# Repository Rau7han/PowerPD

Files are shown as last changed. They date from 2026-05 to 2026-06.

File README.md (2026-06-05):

# PowerPD - ESP32 USB-C PD/PPS Programmable Power Supply

<div align="center">
  
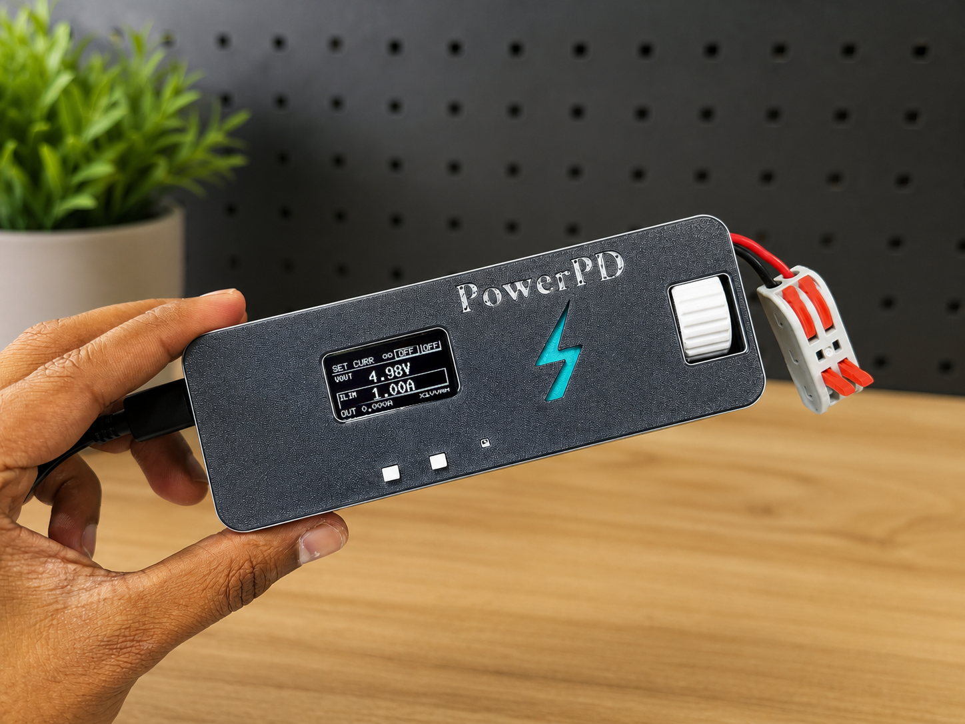
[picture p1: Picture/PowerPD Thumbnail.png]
PowerPD Thumbnail


**A Compact, Feature-Rich USB-C Power Delivery Programmable Bench Power Supply**





</div>

---

## 📋 Table of Contents

- [Introduction](#introduction)
- [Features](#features)
- [Specifications](#specifications)
- [How It Works](#how-it-works)
- [Hardware Overview](#hardware-overview)
- [Gallery](#gallery)
- [Repository Files](#repository-files)
- [Getting Started](#getting-started)
- [Project Links](#project-links)
- [License & Author](#license--author)

---

## Introduction

PowerPD is an innovative ESP32-based **USB-C Power Delivery (PD) and Power Profile Specification (PPS)** programmable bench power supply. It leverages modern USB-C PD technology to provide a flexible, programmable power source that can deliver various voltage and current levels. 

Perfect for **electronics enthusiasts, makers, and professionals** who need a compact, feature-rich power supply for prototyping, testing, and DIY projects.

---

## ✨ Features

- ⚡ **USB-C Power Delivery Support** - Harness power from modern USB-C PD chargers (5V-20V)
- 🎛️ **Programmable Voltage & Current** - User-configurable output with real-time control
- 🔧 **ESP32 Powered** - Full-featured microcontroller for advanced functionality
- 📱 **Interactive Menu System** - Intuitive interface for easy configuration
- 📊 **Real-time Monitoring** - Display current voltage and current output
- 🎓 **Easy Programming** - UART to USB interface for firmware updates
- 💾 **Compact Design** - Space-efficient bench power supply form factor
- 🏗️ **Open Source** - All designs, schematics, and code included

---

## Specifications

| Parameter | Value |
|---|---|
| **Microcontroller** | ESP32 |
| **Input** | USB-C Power Delivery / PPS Charger |
| **Output Voltage Range** | 5V to 20V (via USB PD/PPS protocols) |
| **Programmable Voltage** | User-configurable voltage selection |
| **Programmable Current** | User-adjustable current limits |
| **Control Interface** | Interactive menu system via ESP32 |
| **Communication** | UART to USB interface for programming |
| **Form Factor** | Compact bench power supply |

---

## How It Works

The PowerPD system operates through a simple but powerful workflow:

1. **Power Input** 🔌
   - A USB-C PD/PPS charger supplies power to the system
   - The system negotiates the desired voltage with the charger

2. **ESP32 Control** 🧠
   - The ESP32 microcontroller manages voltage negotiation and current limiting
   - The AP33772S power manager IC provides precise voltage and current regulation

3. **User Configuration** ⚙️
   - Users set desired voltage and current values through an intuitive menu interface
   - Real-time feedback shows current operating parameters

4. **Power Output** ⚡
   - The regulated output is available as a programmable bench power supply
   - Suitable for powering various electronics projects and testing scenarios

---

## Hardware Overview

### 3D Model & Design

<div align="center">

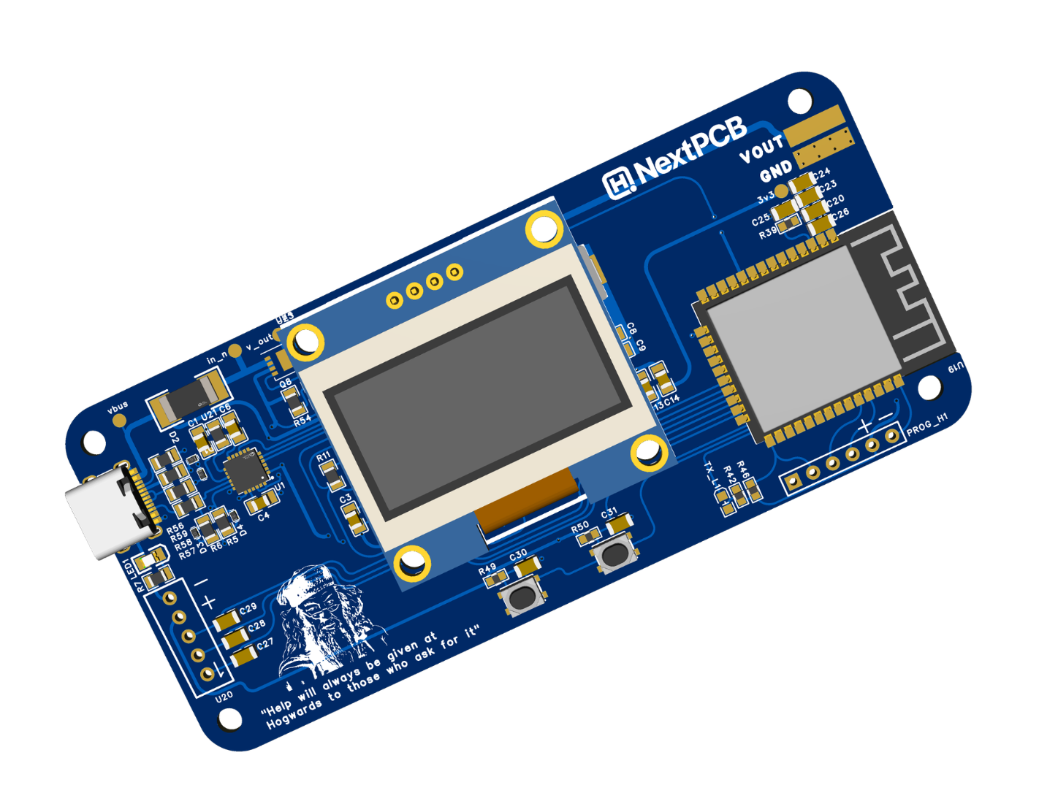
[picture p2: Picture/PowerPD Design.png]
PowerPD 3D Design


**3D Rendered View of PowerPD Enclosure**

</div>

<div align="center">

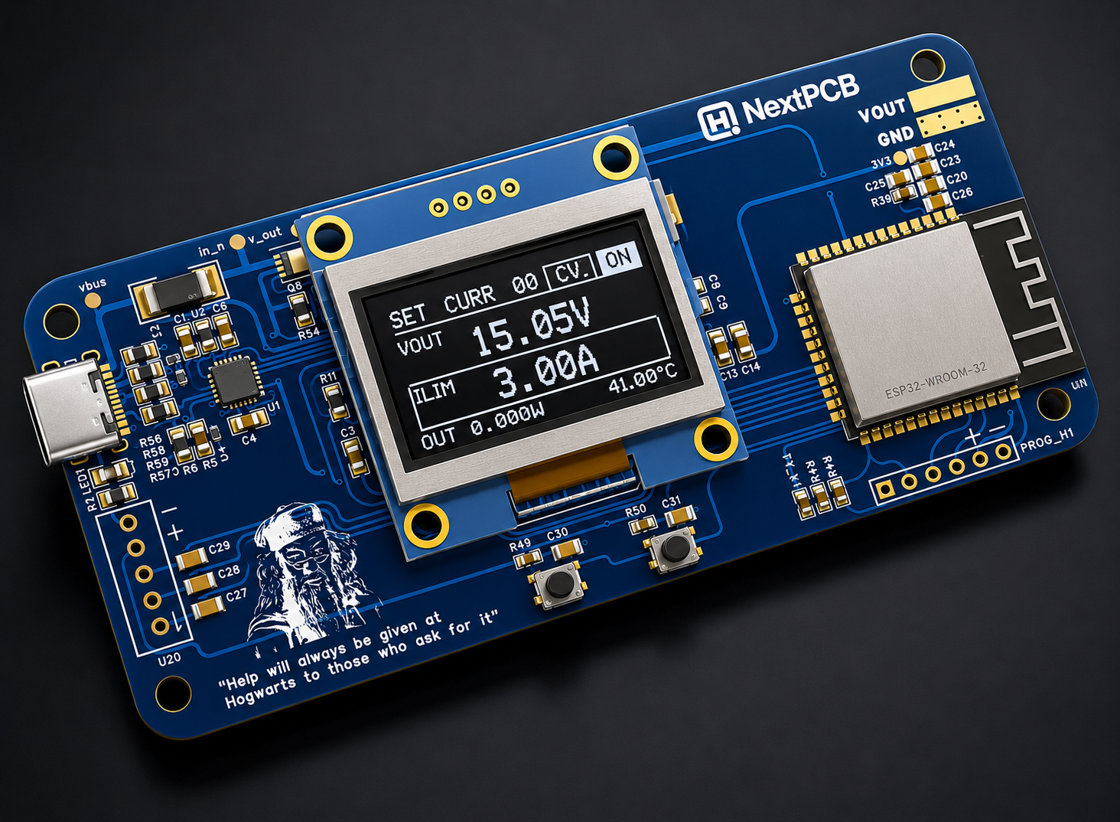
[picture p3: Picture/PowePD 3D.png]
PowerPD 3D Model


**3D-Printable Enclosure Model**

</div>

### PCB & Manufacturing

<div align="center">

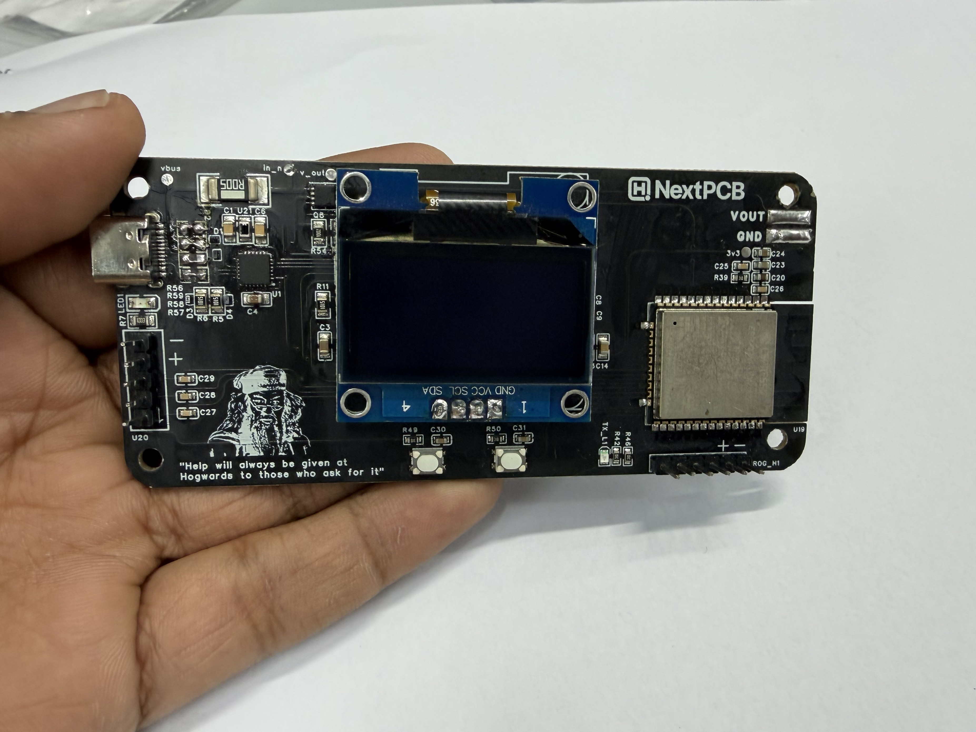
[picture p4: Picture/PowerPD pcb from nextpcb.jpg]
PowerPD PCB


**High-Quality PCB from NextPCB**

</div>

---

## Gallery

### Power Output Demonstrations

<div align="center">

#### 5V Output Mode
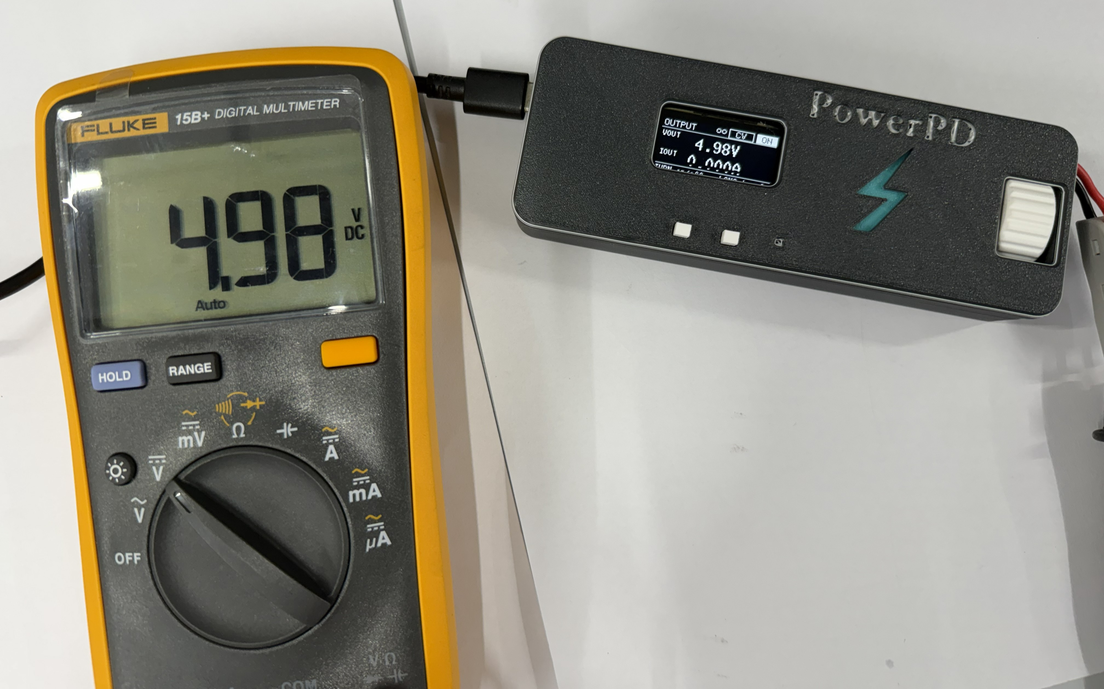
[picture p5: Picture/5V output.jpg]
5V Output


**PowerPD delivering stable 5V output**

</div>

<div align="center">

#### 16V Output Mode
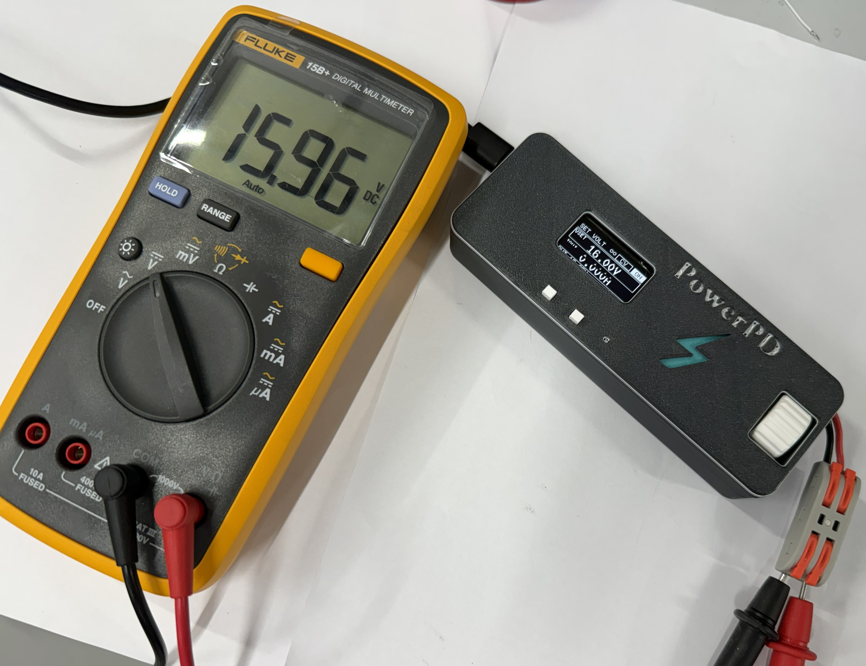
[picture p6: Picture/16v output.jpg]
16V Output


**PowerPD delivering high-voltage 16V output**

</div>

<div align="center">

#### 20V Output Mode
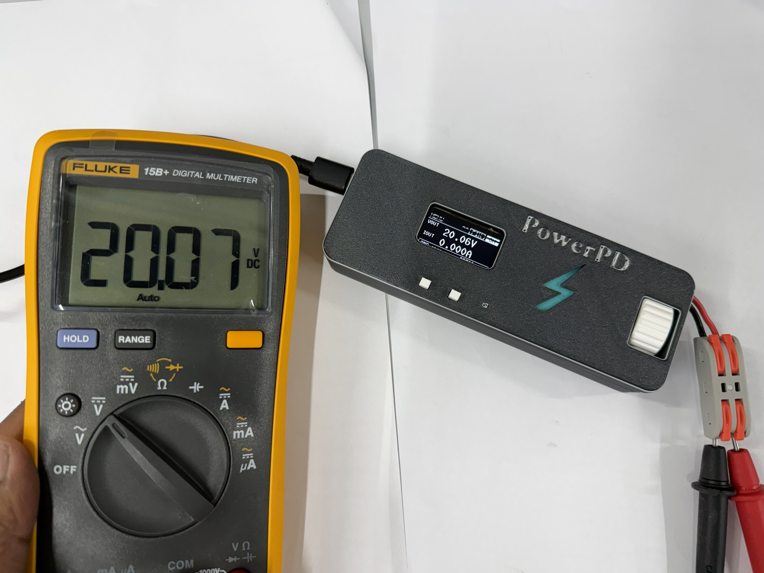
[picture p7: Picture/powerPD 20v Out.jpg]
20V Output


**Maximum 20V output capability**

</div>

<div align="center">

#### Alternative 5V Output View
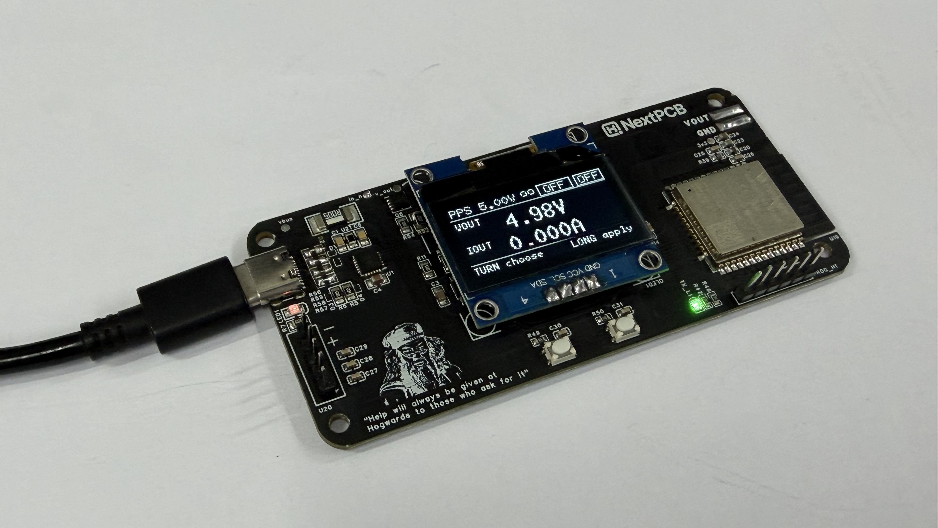
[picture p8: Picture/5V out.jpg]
5V Output Secondary


**5V output measurement configuration**

</div>

<div align="center">

#### 5V Output (Scaled)
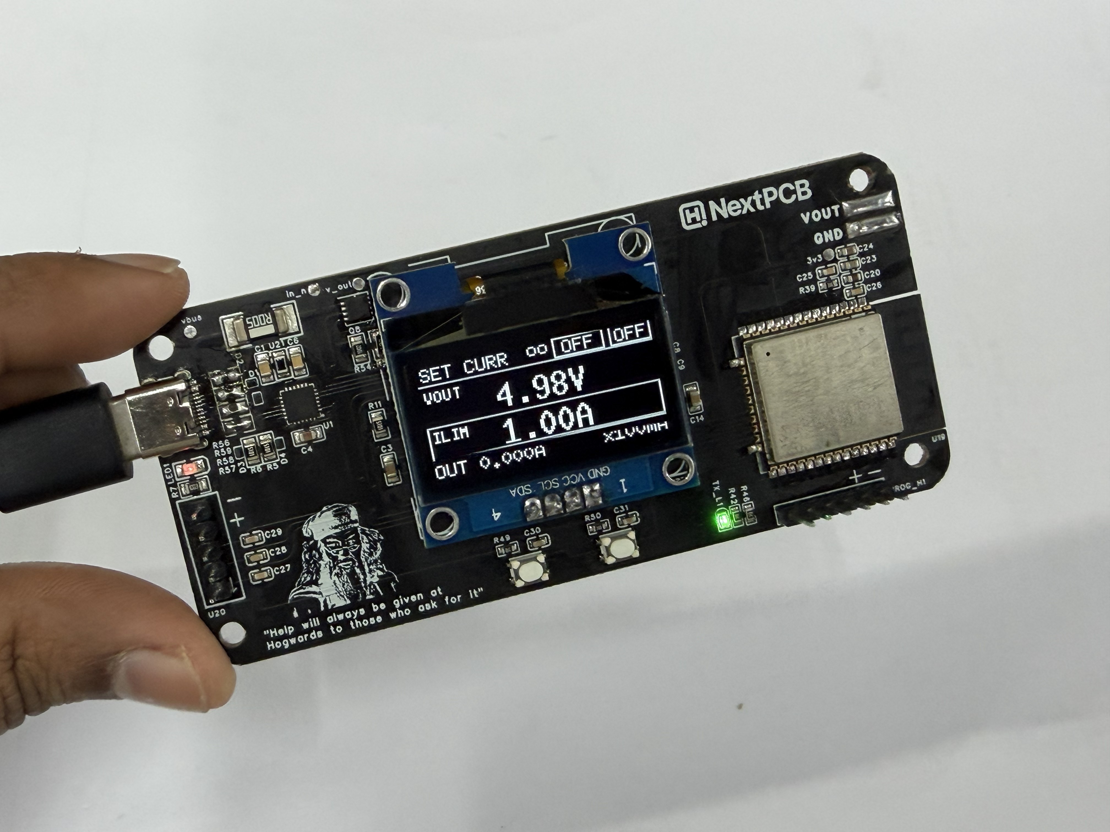
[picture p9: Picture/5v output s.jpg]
5V Output Scaled


**Compact 5V output demonstration**

</div>

### Control Interface & Menu System

<div align="center">

#### Main Menu Display
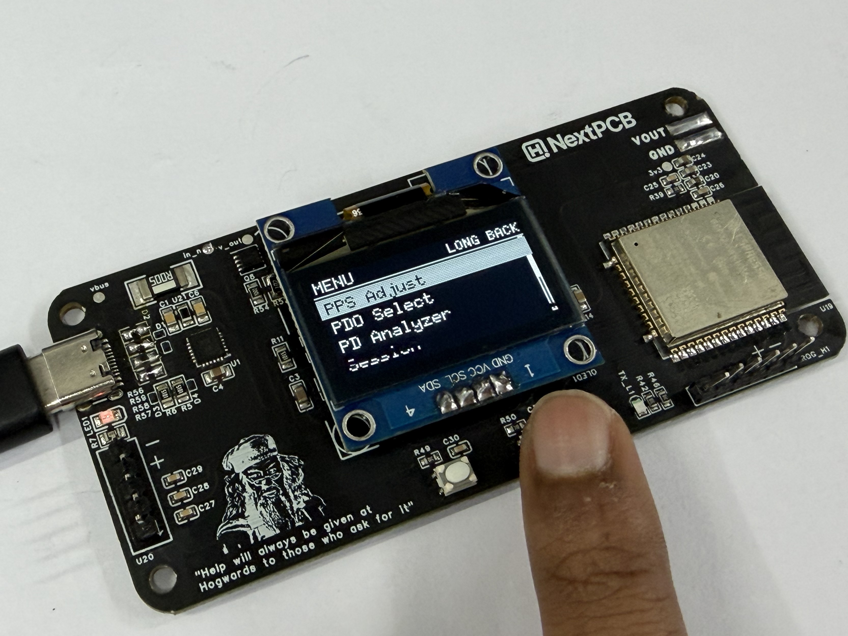
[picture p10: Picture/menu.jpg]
Menu System


**Interactive menu system for voltage/current selection**

</div>

<div align="center">

#### PPS Adjustment Menu
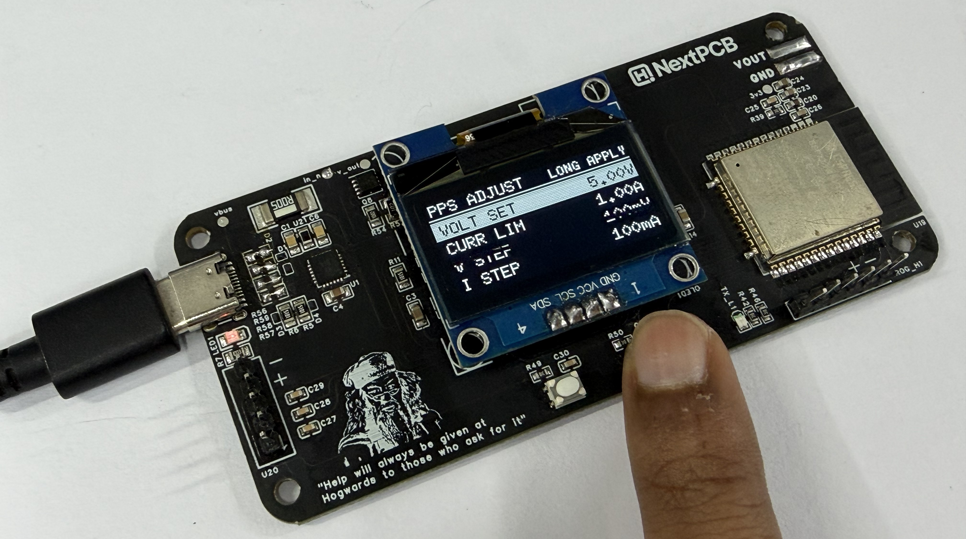
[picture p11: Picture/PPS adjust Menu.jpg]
PPS Menu


**Power Profile Specification (PPS) adjustment interface**

</div>

### Integration & Monitoring

<div align="center">

#### Live Working Setup
PowerPD Working

**PowerPD in action - live demonstration**

</div>

<div align="center">

#### Adafruit IoT Dashboard
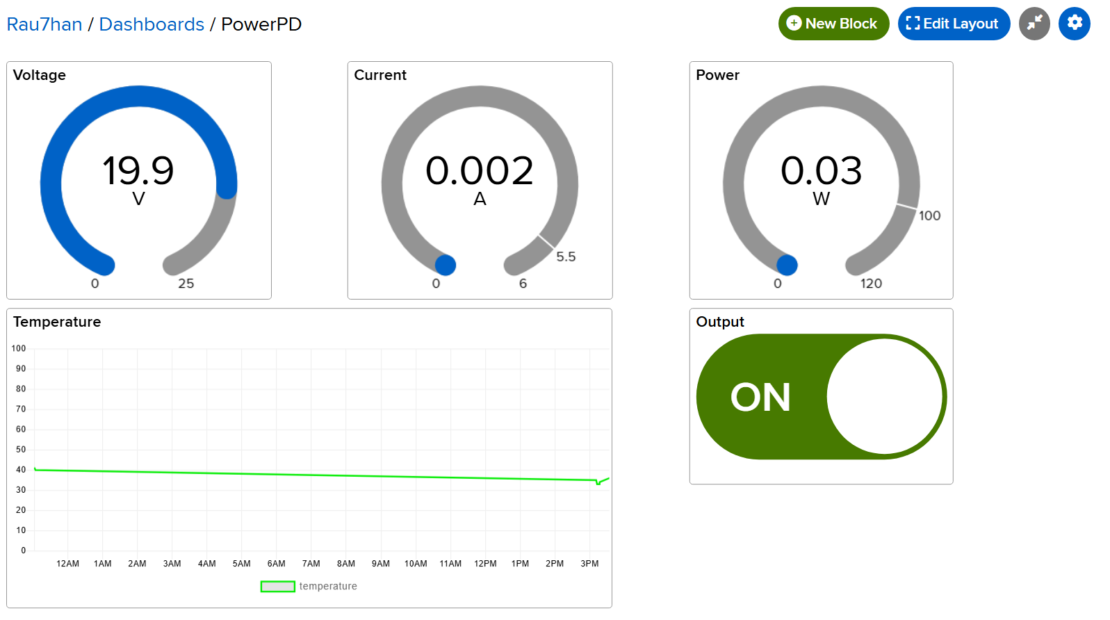
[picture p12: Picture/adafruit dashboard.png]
Adafruit Dashboard


**IoT monitoring with Adafruit IO integration**

</div>

<div align="center">

#### Adafruit IoT Integration
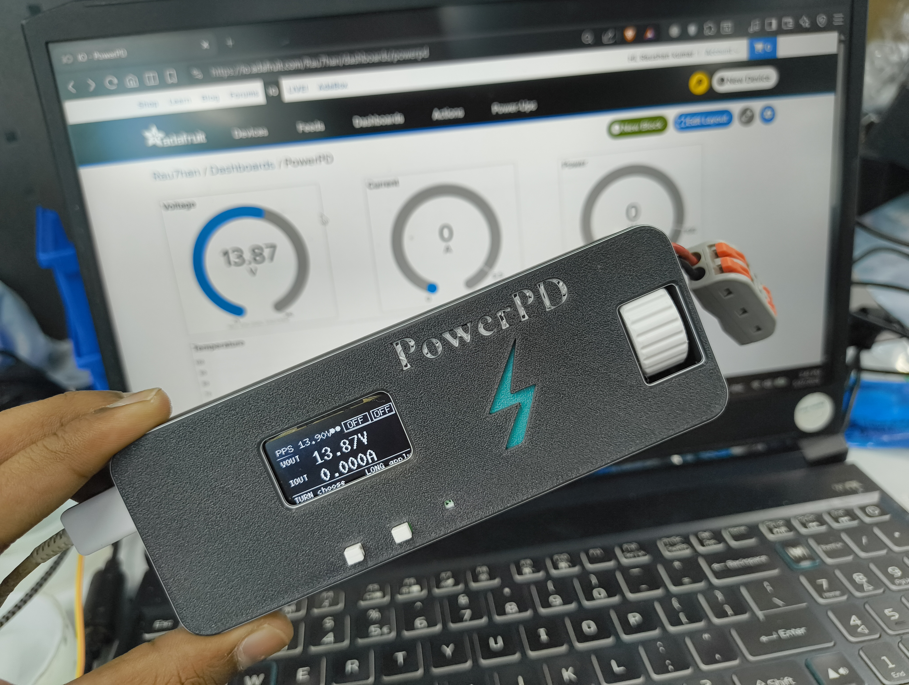
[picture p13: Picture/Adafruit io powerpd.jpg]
Adafruit Integration


**Remote monitoring and control via Adafruit IoT**

</div>

### Development & Programming

<div align="center">

#### Programming Interface
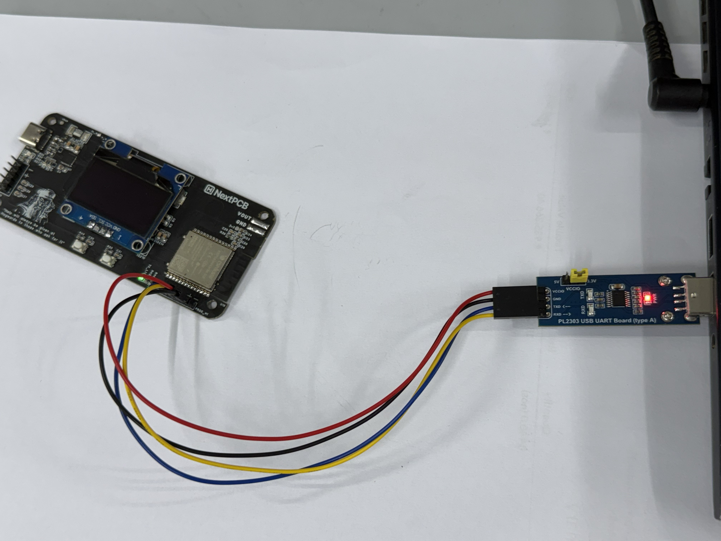
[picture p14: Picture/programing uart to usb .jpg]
UART to USB Programming


**UART to USB interface for firmware programming**

</div>

<div align="center">

#### NextPCB Promotion
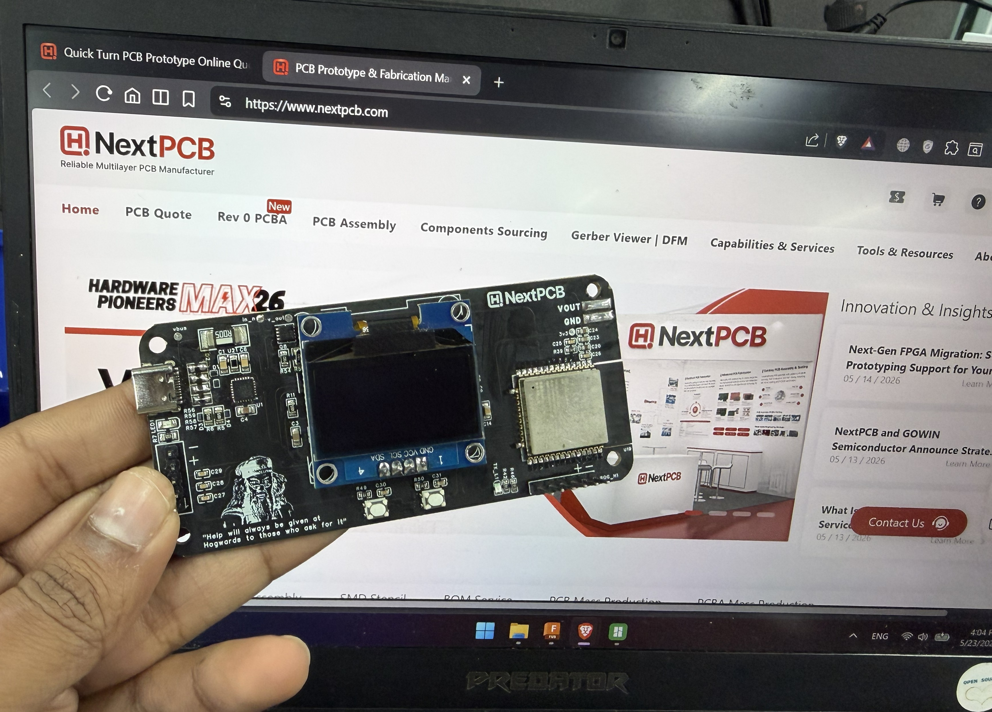
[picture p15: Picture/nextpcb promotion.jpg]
NextPCB Promotion


**PCB fabrication courtesy of NextPCB**

</div>

---

## Repository Files

| Directory | Description |
|---|---|
| **Firmware** | ESP32 Arduino code (`PowerPD.ino`) with AP33772S power manager driver for voltage and current control |
| **Gerber Files** | Complete PCB manufacturing files including schematics BOM and centroid files ready for fabrication |
| **Picture** | High-quality project photos, gallery images, and demonstration screenshots |
| **PowerPD Schematic** | Detailed circuit schematics for reference and replication |
| **STL** | 3D-printable enclosure files for project housing |

---

## Getting Started

### Prerequisites
- ESP32 Development Board or PowerPD PCB
- USB-C Power Delivery (PD) Charger (5V-20V recommended)
- Arduino IDE with ESP32 support
- UART to USB adapter (CH340G or similar) for programming

### Quick Start

1. **Clone/Download the Repository**
   ```bash
   git clone https://github.com/Rau7han/PowerPD.git
   ```

2. **Prepare the Firmware**
   - Open `Firmware/PowerPD.ino` in Arduino IDE
   - Include the `AP33772S.cpp` and `AP33772S.h` libraries
   - Select ESP32 board and appropriate COM port

3. **Upload Firmware**
   - Connect UART to USB adapter to programming header
   - Upload the firmware to your ESP32

4. **Power On**
   - Connect USB-C PD charger to the PowerPD input
   - The system will boot and display the menu

5. **Configure Output**
   - Use the menu system to select desired voltage (5V-20V)
   - Adjust current limits as needed
   - Your programmable power supply is ready to use!

---

## Project Links

| Platform | Link |
|---|---|
| **Hackster.io** | [PowerPD ESP32 USB-C PD/PPS Programmable Power Supply](https://www.hackster.io/rau7han/powerpd-esp32-usb-c-pd-pps-programmable-power-supply-c2c4c0) |
| **Hackaday.io** | [PowerPD - ESP32 USB-C PD/PPS Bench Power Supply](https://hackaday.io/project/205791-powerpd-esp32-usb-c-pdpps-bench-power-supply) |
| **Instructables** | [PowerPD: ESP32 USB-C PD Bench Power Supply](https://www.instructables.com/PowerPD-ESP32-USB-C-PD-Bench-Power-Supply/) |

---

## License & Author

**Author**: [Rau7han](https://github.com/Rau7han)

**License**: See repository for detailed license information

---

<div align="center">

**Contributions, suggestions, and feedback are welcome!** 🎉

If you build PowerPD, we'd love to hear about it! Share your projects and improvements.

</div>

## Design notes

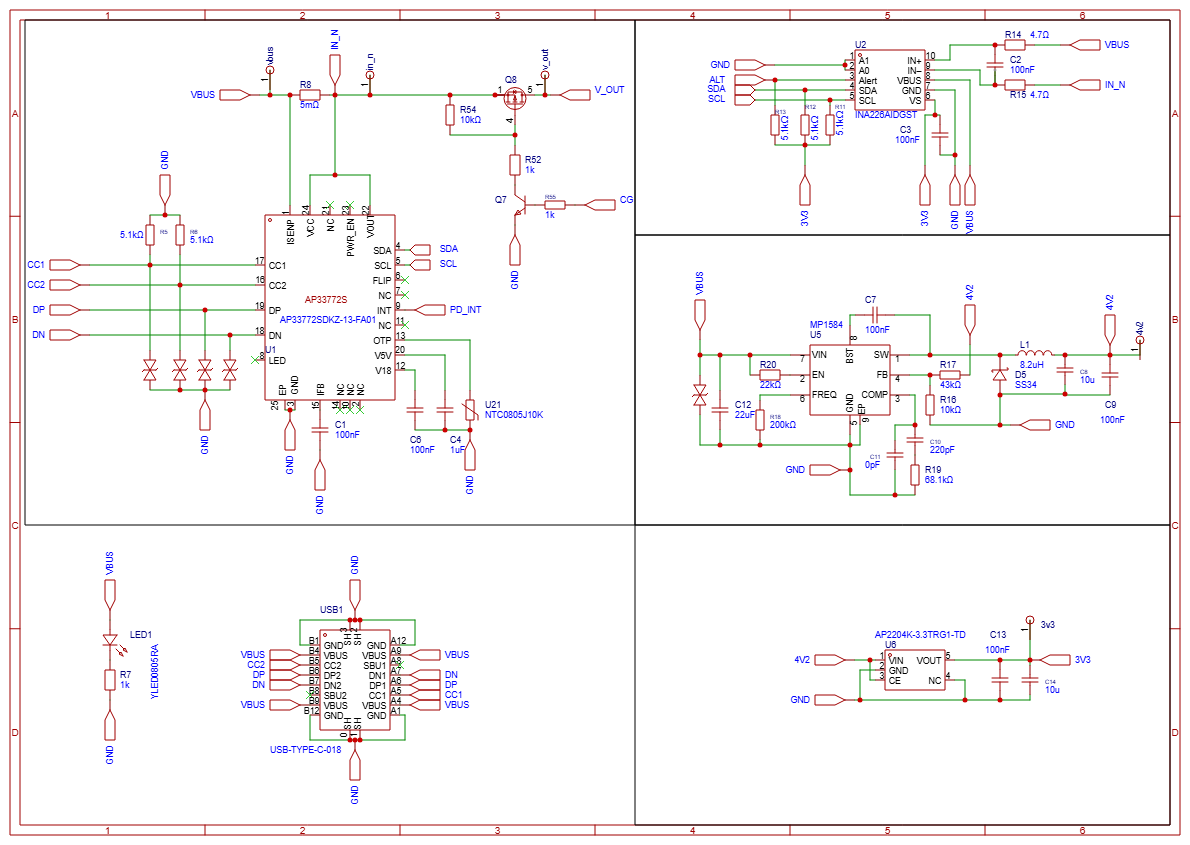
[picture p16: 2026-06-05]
PowerPD Schematic/PowerPD Schematic 1.png

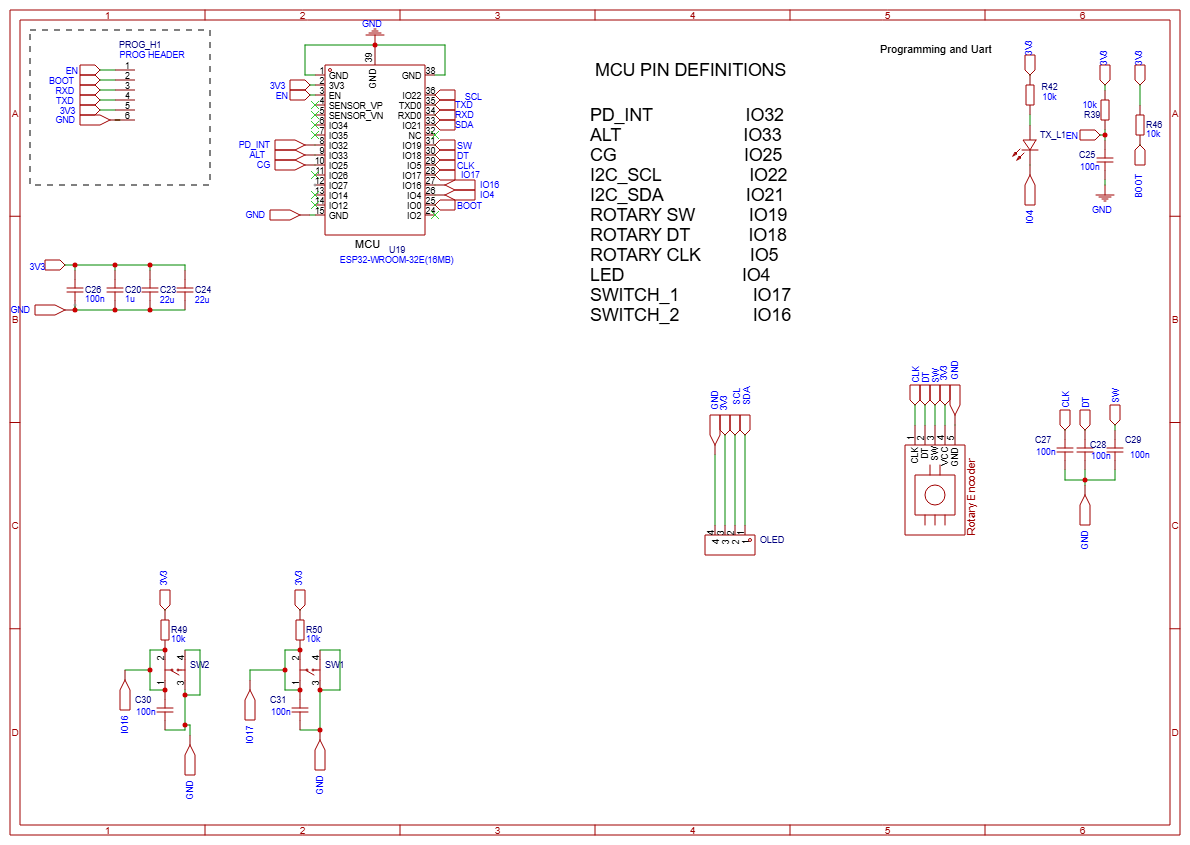
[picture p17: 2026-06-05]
PowerPD Schematic/PowerPD Sch 2.png

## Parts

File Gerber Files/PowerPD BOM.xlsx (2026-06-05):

No. | Quantity | Comment | Designator | Footprint | Value | Manufacturer Part | Manufacturer | Supplier Part | Supplier
1 | 5 | testPoint | 3v3,4v2,in_n,vbus,v_out | testPoint
2 | 5 | 100nF | C1,C6,C7,C9,C13 | C0805 | 100nF | C0805B104K100NT | TORCH(火炬) | C17702773 | LCSC
3 | 2 | 100nF | C2,C3 | C0805 | 100nF | CT41G-0805-2X1-50V-0.1uF-M(N) | TORCH(火炬) | C138340 | LCSC
4 | 1 | 1uF | C4 | C0805 | 1uF | NC0805B105K101CDDN | HUI JU(汇聚) | C19185643 | LCSC
5 | 2 | 10u | C8,C14 | C0805 | 10u | CL21B224KBFNNNE | SAMSUNG(三星) |  | LCSC
6 | 1 | 220pF | C10 | C0805 | 220pF | CC0805KRX7R9BB221 | YAGEO(国巨) | C107145 | LCSC
7 | 1 | 0pF | C11 | C0805 | 0pF | CC0805KRX7R9BB221 | YAGEO(国巨) |  | LCSC
8 | 1 | 22uF | C12 | C0805 | 22uF | CL21A226MAQNNNE | SAMSUNG(三星) | C45783 | LCSC
9 | 1 | 1u | C20 | C0603
10 | 2 | 22u | C23,C24 | C0603
11 | 6 | 100n | C25,C27,C28,C29,C30,C31 | C0603 |  | 0805 | null | C9900012713 | LCSC
12 | 1 | 100n | C26 | C0603
 | 4 | D5V0H1B2LP-7B | D1,D2,D3,D4 |  |  | D5V0H1B2LP-7B
13 | 1 | PESD1ETH1GXLS-QYL | D6 | SOD-882_L1.0-W0.6-BI-1 |  | PESD1ETH1GXLS-QYL | Nexperia(安世) | C553450 | LCSC
14 | 1 | SS34 | D5 | SMA_L4.3-W2.6-LS5.2-RD |  | SS34 | MDD(辰达半导体) | C8678 | LCSC
15 | 1 | 8.2uH | L1 | IND-SMD_L7.3-W6.8 | 8.2uH | MWSA0603S-8R2MT | Sunlord(顺络) | C408450 | LCSC
16 | 1 | A-SP170R5C-A01-3T | LED1 | LED0805-FD |  | A-SP170R5C-A01-3T | YONGYUTAI(永裕泰) | C52989003 | LCSC
17 | 1 | OLED_4P_1.3\"-128*64 | OLED1 | OLED_4P_1.3\"-128*64 |  | DLC0130ANOB-W | DLC Display Co.,Ltd
18 | 1 | PROG HEADER | PROG_H1 | HDR-M-2.54_1X6 |  | New SchematicLib
19 | 1 | S8050 J3Y(RANGE:200-350) | Q7 | SOT-23-3_L3.0-W1.7-P0.95-LS2.9-BR |  | S8050 J3Y(RANGE:200-350) | CJ(江苏长电/长晶) | C2146 | LCSC
20 | 1 | Transistor_FET_DMP3013SFV | Q8 | Package_SON:Diodes_PowerDI3333-8 | DMP3013SFV-7
21 | 5 | 5.1kΩ | R5,R6,R11,R12,R13 | R0805 | 5.1kΩ | AC0805FR-075K1L | Tyohm(幸亚电阻) | C269748 | LCSC
22 | 2 | 1k | R7,R52 | R0805 | 1k | CRG0805F100K | TE Connectivity(泰科电子) |  | LCSC
23 | 1 | 5mΩ | R8 | RES-SMD_L6.4-W3.2-1 | 5mΩ | PA2512FKF070R005E | YAGEO(国巨) | C723365 | LCSC
24 | 2 | 4.7Ω | R14,R15 | R0805 | 4.7Ω | SCR0805F4R7 | VO(翔胜) | C3016578 | LCSC
25 | 2 | 10kΩ | R16,R54 | R0805 | 10kΩ | 0805W8F1002T5E | UNI-ROYAL(厚声) | C17414 | LCSC
26 | 1 | 43kΩ | R17 | R0805 | 43kΩ | CR0805F84302G | LIZ(丽智电子) | C101724 | LCSC
27 | 1 | 200kΩ | R18 | R0805 | 200kΩ | 0805W8F2003T5E | UNI-ROYAL(厚声) | C17539 | LCSC
28 | 1 | 68.1kΩ | R19 | R0805 | 68.1kΩ | ARG05FTC6812N | Viking(光颉) | C218668 | LCSC
29 | 1 | 22kΩ | R20 | R0805 | 22kΩ | AS05W2J0223T5E |  | C560511 | LCSC
30 | 5 | 10k | R39,R42,R46,R49,R50 | R0603 |  | 0805 | null | C9900012714 | LCSC
31 | 1 | 1k | R55 | R0805 | 1k | RC0805FR-071KL | Tyohm(幸亚电阻) |  | LCSC
32 | 4 | 0R | R56,R57,R58,R59 | R0805 | 0R | CRG0805F100K | TE Connectivity(泰科电子) |  | LCSC
33 | 2 | TSA016A2526B | SW1,SW2 | KEY-SMD_4P-L4.2-W3.4-P2.15-LS4.5-TL |  | TSA016A2526B | BZCN(博众电气) | C2888429 | LCSC
34 | 1 | D21121300350-LED0805 | TX_L1 | LED0603-FD |  | D21121300350-LED0805 | null | C9900003974 | LCSC
35 | 1 | AP33772SDKZ-13-FA01 | U1 | QFN-24_L4.0-W4.0-P0.50-TL-EP2.8 |  | AP33772SDKZ-13-FA01 | DIODES(美台) | C24374260 | LCSC
36 | 1 | INA226AIDGST | U2 | VSSOP-10_L3.0-W3.0-P0.50-LS4.9-BL |  | INA226AIDGST | TI(德州仪器) | C2653870 | LCSC
37 | 1 | MP1584 | U5 | SOIC-8_L5.0-W4.0-P1.27-LS6.0-BL-EP |  | MP1584EN-LF-Z | MPS | C15051 | LCSC
38 | 1 | AP2204K-3.3TRG1-TD | U6 | SOT-23-5_L3.0-W1.7-P0.95-LS2.8-BL |  | AP2204K-3.3TRG1-TD | TDSEMIC(拓电半导体) | C42421817 | LCSC
39 | 1 | ESP32-WROOM-32E(16MB) | U19 | WIFI-SMD_ESP32-WROOM-32E |  | ESP32-WROOM-32E-N16 | ESPRESSIF(乐鑫) | C701343 | LCSC
40 | 1 | Rotary_Encoder_Module | U20 | ROTARY_ENCODER_MODULE |  | PZ2.54-1X5-11.2
41 | 1 | NTC0805J10K | U21 | R0805 |  | NTC0805J10K | TE Connectivity(泰科电子) | C17376775 | LCSC
42 | 1 | USB-TYPE-C-018 | USB1 | USB-C_SMD-TYPE-C-31-M-12 |  | USB-TYPE-C-018 | DEALON(德艺隆) | C2927038 | LCSC

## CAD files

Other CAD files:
STL/PowePD.f3z

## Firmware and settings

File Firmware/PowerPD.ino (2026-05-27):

/**
 * Hardware:
 *   ESP32, AP33772S PD sink, INA226, SH1106 128x64 OLED,
 *   Rotary encoder (CLK/DT/SW), optional SW1, optional SW2, MOSFET
 *
 * ENCODER-ONLY OPERATION (buttons are optional shortcuts):
 *   Main screen:
 *     Rotate       → adjust selected field value
 *     Short press  → cycle field: PROFILE→VSET→ILIM→OUTPUT→MENU→…
 *     Long press   → PROFILE: apply profile
 *                    VSET/ILIM: apply PPS settings
 *                    OUTPUT: toggle ON/OFF
 *                    MENU: open menu
 *
 *   Menu / sub-screens:
 *     Rotate       → move cursor / scroll
 *     Short press  → enter item / toggle / advance sub-field
 *     Long press   → back / apply & return
 *
 * Optional shortcuts:
 *   SW1 short  → toggle VSET / ILIM on main
 *   SW1 long   → open menu
 *   SW2 short  → toggle output ON/OFF
 *   SW2 long   → jump to session screen
 */

// ============================================================
//  INCLUDES
// ============================================================
#include <Arduino.h>
#include <Wire.h>
#include <U8g2lib.h>
#include <Preferences.h>
#include <WiFi.h>
#include <PubSubClient.h>
#include "AP33772S.h"
#include <INA226.h>

// ============================================================
//  USER CONFIG — edit before flashing
// ============================================================
#define WIFI_SSID        "ESP"
#define WIFI_PASSWORD    "abcd1234"
#define AIO_SERVER       "io.adafruit.com"
#define AIO_PORT         1883
#define AIO_USERNAME     "Rau7han"
#define AIO_KEY          "aio_wxZc81qgBirIGZ7VoX7LTOo6VrA9"
#define AIO_FEED_PREFIX   AIO_USERNAME "/feeds/"

// ============================================================
//  PIN MAP
// ============================================================
static constexpr uint8_t PIN_SDA         = 21;
static constexpr uint8_t PIN_SCL         = 22;
static constexpr int8_t  PIN_INT         = 32;
static constexpr uint8_t PIN_LED         = 4;
static constexpr uint8_t PIN_MOSFET      = 25;
static constexpr uint8_t PIN_ENC_CLK     = 5;
static constexpr uint8_t PIN_ENC_DT      = 18;
static constexpr uint8_t PIN_ENC_SW      = 19;
static constexpr uint8_t PIN_SW1         = 17;   // optional
static constexpr uint8_t PIN_SW2         = 16;   // optional

static constexpr uint8_t ADDR_AP         = 0x52;
static constexpr uint8_t ADDR_INA        = 0x40;
static constexpr uint8_t ADDR_OLED       = 0x3C;

// ============================================================
//  CONSTANTS
// ============================================================
static constexpr uint16_t PPS_DEFAULT_MV  = 5000;
static constexpr float    INA_SHUNT_OHM   = 0.005f;
static constexpr float    INA_MAX_AMPS    = 6.0f;
static constexpr float    OVP_LIMIT_V     = 22.0f;
static constexpr float    OCP_LIMIT_A     = 5.5f;
static constexpr int8_t   OTP_LIMIT_C     = 80;

// Timing (ms)
static constexpr uint32_t T_DEBOUNCE      = 30;
static constexpr uint32_t T_LONGPRESS     = 650;
static constexpr uint32_t T_DISPLAY       = 60;
static constexpr uint32_t T_MEASURE       = 100;
static constexpr uint32_t T_HOTPLUG       = 800;
static constexpr uint32_t T_PPS_KEEPALIVE = 4500;
static constexpr uint32_t T_PDO_POLL      = 200;
static constexpr uint32_t T_PDO_TIMEOUT   = 6000;
static constexpr uint32_t T_NEGO_WAIT     = 1500;
static constexpr uint32_t T_WIFI_RETRY    = 15000;
static constexpr uint32_t T_MQTT_RETRY    = 5000;
static constexpr uint32_t T_CLOUD_DEF     = 15000;
static constexpr uint32_t T_ANALYZER_REFRESH = 2000;  // PD Analyzer refresh interval

// Display EMA smoothing
static constexpr float    EMA_K           = 6.0f;

// Step tables
static const uint16_t V_STEPS[]    = { 20, 100, 1000 };
static constexpr uint8_t V_STEP_N  = 3;
static const uint16_t I_STEPS[]    = { 50, 100, 500 };
static constexpr uint8_t I_STEP_N  = 3;
static const uint32_t CLOUD_RATES[]   = { 15000, 30000, 60000 };
static constexpr uint8_t CLOUD_RATE_N = 3;

// ============================================================
//  ENUMS
// ============================================================
enum class Screen : uint8_t {
    MAIN = 0, MENU,
    PPS_ADJUST, PDO_SELECT, PD_ANALYZER,
    SESSION, CLOUD, SAFETY, SYSTEM,
    FAULT, DISCONNECTED, DETECTING
};

// Fields cycled on MAIN by short-press
enum class MainField : uint8_t {
    FIELD_PROFILE = 0,
    FIELD_VSET,
    FIELD_ILIM,
    FIELD_OUTPUT,
    FIELD_MENU,
    FIELD_COUNT
};

enum class SysMode : uint8_t {
    DISCONNECTED, DETECTING, LEGACY, PD_FIXED, PPS, FAULT
};

// ============================================================
//  STATE STRUCTS
// ============================================================
struct SysState {
    SysMode  mode           = SysMode::DISCONNECTED;
    bool     ppsAvail       = false;

    uint8_t  fixedIdx[AP33772S_MAX_PDO] = {};
    uint8_t  fixedCount     = 0;
    uint8_t  fixedSel       = 0;

    uint8_t  ppsPdoIdx      = 0;
    uint16_t ppsSetV_mV     = PPS_DEFAULT_MV;
    uint16_t ppsSetI_mA     = 3000;
    uint16_t ppsMinV_mV     = 3300;
    uint16_t ppsMaxV_mV     = 21000;
    uint16_t ppsMaxI_mA     = 3000;
    uint16_t negoV_mV       = 0;
    uint16_t negoI_mA       = 0;

    // Raw values
    float    rawV           = 0.0f;
    float    rawI           = 0.0f;
    float    rawP           = 0.0f;

    // EMA-smoothed values for OLED
    float    dispV          = 0.0f;
    float    dispI          = 0.0f;
    float    dispP          = 0.0f;

    int8_t   temp_C         = 25;
    bool     outputReq      = false;
    bool     mosfetOn       = false;
    bool     fault          = false;
    char     faultMsg[32]   = "";
    uint8_t  faultCount     = 0;
    uint8_t  negoFails      = 0;
    bool     ovpEn          = true;
    bool     otpEn          = true;
} sys;

struct UIState {
    Screen    screen        = Screen::DETECTING;
    MainField mainField     = MainField::FIELD_PROFILE;

    // Profile cursor for home screen: 0..fixedCount-1 = fixed, fixedCount = PPS
    uint8_t   profileCursor = 0;

    uint8_t   cursor        = 0;
    uint8_t   scrollOff     = 0;

    // PPS Adjust: 0=VSET 1=ILIM 2=V STEP 3=I STEP
    uint8_t   ppsField      = 0;

    uint8_t   vStepIdx      = 1;   // 100mV default
    uint8_t   iStepIdx      = 1;   // 100mA default
    uint8_t   cloudRateIdx  = 1;   // 2s default

    // Safety cursor: 0=OVP 1=OTP
    uint8_t   safetyCursor  = 0;

    // PD Analyzer
    uint8_t   analyzerRow   = 0;
    bool      analyzerDetail = false;
} ui;

struct Session {
    uint32_t startMs       = 0;
    uint32_t lastSampleMs  = 0;
    double   wh            = 0.0;
    double   ah            = 0.0;
    float    peakW         = 0.0f;
    float    peakA         = 0.0f;
} sess;

struct CloudState {
    bool     wifiOk        = false;
    bool     mqttOk        = false;
    uint32_t lastTxMs      = 0;
    uint32_t interval      = T_CLOUD_DEF;
    char     ipStr[16]     = "0.0.0.0";
} cloud;

// Menu items — order must match MAP[] in handleMenu()
static const char* const MENU_ITEMS[] = {
    "PPS Adjust", "PDO Select", "PD Analyzer",
    "Session", "Cloud", "Safety", "System"
};
static constexpr uint8_t MENU_COUNT = 7;

// ============================================================
//  PERIPHERALS
// ============================================================
AP33772S pd(Wire, PIN_INT);
INA226   ina(ADDR_INA, &Wire);
U8G2_SH1106_128X64_NONAME_F_HW_I2C u8g2(U8G2_R2, U8X8_PIN_NONE);
Preferences prefs;
WiFiClient  wifiClient;
PubSubClient mqtt(wifiClient);

// ============================================================
//  BUTTON
// ============================================================
struct Button {
    uint8_t  pin;
    bool     lastRaw   = false;
    bool     state     = false;
    bool     longFired = false;
    uint32_t bounceMs  = 0;
    uint32_t pressMs   = 0;

    void begin(uint8_t p) { pin = p; pinMode(p, INPUT_PULLUP); }

    uint8_t poll() {
        bool raw = (digitalRead(pin) == LOW);
        uint32_t now = millis();
        if (raw != lastRaw) { lastRaw = raw; bounceMs = now; }
        if (now - bounceMs < T_DEBOUNCE) return 0;
        if (raw != state) {
            state = raw;
            if (state) { pressMs = now; longFired = false; }
            else if (!longFired) return 1;
        } else if (state && !longFired && now - pressMs >= T_LONGPRESS) {
            longFired = true; return 2;
        }
        return 0;
    }
};

Button encSw, sw1, sw2;

// ============================================================
//  ENCODER
// ============================================================
static const int8_t ENC_TABLE[] = {0,-1,1,0, 1,0,0,-1, -1,0,0,1, 0,1,-1,0};
volatile uint8_t encRaw = 0;
volatile int16_t encAcc = 0;

void IRAM_ATTR isrEnc() {
    encRaw = (encRaw << 2) | ((digitalRead(PIN_ENC_CLK) << 1) | digitalRead(PIN_ENC_DT));
    encAcc += ENC_TABLE[encRaw & 0x0F];
}

int readEncoder() {
    noInterrupts(); int16_t acc = encAcc; interrupts();
    int det = acc / 4;
    if (!det) return 0;
    noInterrupts(); encAcc -= det * 4; interrupts();
    return det;
}

// ============================================================
//  SOFT TIMER
// ============================================================
struct SoftTimer {
    uint32_t last = 0;
    bool due(uint32_t p) {
        if (millis() - last >= p) { last = millis(); return true; }
        return false;
    }
};
SoftTimer tmDisplay, tmMeasure, tmHotplug, tmPPS, tmCloud, tmWifi, tmMqtt, tmAnalyzer;

// ============================================================
//  FORWARD DECLARATIONS
// ============================================================
void pdInit(); bool pdWaitPDOs(uint32_t t); void pdDetect(); void pdApply(bool smooth);
void mosfetUpdate(); void faultTrigger(const char* m); void faultClear();
void safetyCheck(); void sessionUpdate(); void nvLoad(); void nvSave();
void cloudConnect();
void cloudPublish();
void mqttCallback(char* topic, byte* payload, unsigned int length);


// Profile helpers
uint8_t  profileTotal();
bool     profileCursorIsPPS();
void     syncProfileCursorFromActiveMode();
void     applyProfileCursor();
void     formatProfileLabel(char* buf, size_t len, uint8_t cursor);
void     formatActiveProfileLabel(char* buf, size_t len);

// Render functions
void renderMain(); void renderMenu(); void renderPPSAdjust(); void renderPDOSelect();
void renderPDAnalyzer();
void renderSession(); void renderCloud(); void renderSafety(); void renderSystem();
void renderFault(); void renderDisconnected(); void renderDetecting();

// Input handlers
void handleMain(int, uint8_t, uint8_t, uint8_t);
void handleMenu(int, uint8_t, uint8_t, uint8_t);
void handlePPSAdjust(int, uint8_t, uint8_t, uint8_t);
void handlePDOSelect(int, uint8_t, uint8_t, uint8_t);
void handlePDAnalyzer(int, uint8_t, uint8_t, uint8_t);
void handleSession(int, uint8_t, uint8_t, uint8_t);
void handleCloud(int, uint8_t, uint8_t, uint8_t);
void handleSafety(int, uint8_t, uint8_t, uint8_t);
void handleSystem(int, uint8_t, uint8_t, uint8_t);

// Display helpers
void setFontS(); void setFontM(); void setFontL();
void dStr(uint8_t x, uint8_t y, const char* s);
void dStrC(uint8_t y, const char* s);
void dStrR(uint8_t y, const char* s);
void dHLine(uint8_t y);
void dHighlightRow(uint8_t y_top, uint8_t h);
void dHeader(const char* title, const char* right);
void dFooter(const char* msg);
void dBadge(uint8_t x, uint8_t y, uint8_t w, const char* label, bool filled);
void dRow(uint8_t yb, const char* left, const char* right, bool selected);
void dScrollBar(uint8_t total, uint8_t visible, uint8_t offset);
void dMeterBar(uint8_t x, uint8_t y, uint8_t w, uint8_t h, float fraction);
const char* modeLabelShort();
const char* mainFieldTitle();
float activeCurrentLimitA();

// ============================================================
//  PROFILE HELPERS
// ============================================================

uint8_t profileTotal() {
    return sys.fixedCount + (sys.ppsAvail ? 1 : 0);
}

bool profileCursorIsPPS() {
    return sys.ppsAvail && (ui.profileCursor == sys.fixedCount);
}

void syncProfileCursorFromActiveMode() {
    uint8_t total = profileTotal();

    if (total == 0) {
        ui.profileCursor = 0;
        return;
    }

    if (sys.mode == SysMode::PPS && sys.ppsAvail) {
        ui.profileCursor = sys.fixedCount;
        return;
    }

    if (sys.mode == SysMode::PD_FIXED && sys.fixedSel < sys.fixedCount) {
        ui.profileCursor = sys.fixedSel;
        return;
    }

    ui.profileCursor = 0;
}


void applyProfileCursor() {
    if (profileCursorIsPPS()) {
        sys.mode = SysMode::PPS;
        sys.ppsSetV_mV = constrain(sys.ppsSetV_mV, sys.ppsMinV_mV, sys.ppsMaxV_mV);
        sys.ppsSetI_mA = constrain(sys.ppsSetI_mA, (uint16_t)1000u, sys.ppsMaxI_mA);
        pdApply(false);
    } else if (ui.profileCursor < sys.fixedCount) {
        sys.fixedSel = ui.profileCursor;
        sys.mode = SysMode::PD_FIXED;
        pdApply(false);
    }
}
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
void loop() {
    pd.task();

    // PPS keepalive
    if (sys.mode == SysMode::PPS && sys.mosfetOn && tmPPS.due(T_PPS_KEEPALIVE))
        pd.setPPSPDO(sys.ppsPdoIdx, sys.ppsSetV_mV, sys.ppsSetI_mA);

    // Measurement
    if (tmMeasure.due(T_MEASURE)) {
        float rv = ina.getBusVoltage();
        float ri = ina.getCurrent();
        sys.rawV = (rv > 0) ? rv : 0.0f;
        sys.rawI = (ri > 0) ? ri : 0.0f;
        sys.rawP = sys.rawV * sys.rawI;
        sys.temp_C = pd.getTemperature_C();

        float a = 1.0f / EMA_K;
        sys.dispV = sys.dispV + a * (sys.rawV - sys.dispV);
        sys.dispI = sys.dispI + a * (sys.rawI - sys.dispI);
        sys.dispP = sys.dispV * sys.dispI;

        safetyCheck();
        sessionUpdate();
    }

    // Hotplug
    if (tmHotplug.due(T_HOTPLUG)) {
        bool charger = (pd.getOpMode() & (OPMODE_PDMOD | OPMODE_LGCYMOD)) != 0;
        bool active  = (sys.mode != SysMode::DISCONNECTED && sys.mode != SysMode::DETECTING);
        if (charger && !active) {
            sys.mode = SysMode::DETECTING; ui.screen = Screen::DETECTING;
            delay(150);
            if (pdWaitPDOs(T_PDO_TIMEOUT) && sys.mode != SysMode::LEGACY) pdDetect();
            syncProfileCursorFromActiveMode();
        } else if (!charger && active) {
            sys.mode = SysMode::DISCONNECTED;
            ui.screen = Screen::DISCONNECTED;

            sys.outputReq = false;
            sys.fault = false;

            sys.fixedCount = 0;
            sys.ppsAvail = false;
            sys.ppsPdoIdx = 0;
            sys.negoV_mV = 0;
            sys.negoI_mA = 0;
            ui.profileCursor = 0;

            mosfetUpdate();
        } else if (active && !sys.fault && pd.isFault()) {
            String f = pd.getFaultString();
            faultTrigger(f.c_str());
        }
    }

    // Input
    int     dir = readEncoder();
    uint8_t enc = encSw.poll();
    uint8_t b1  = sw1.poll();
    uint8_t b2  = sw2.poll();

    if (sys.fault) {
        if (enc || b1 || b2) faultClear();
    } else {
        switch (ui.screen) {
            case Screen::MAIN:        handleMain(dir, enc, b1, b2);       break;
            case Screen::MENU:        handleMenu(dir, enc, b1, b2);       break;
            case Screen::PPS_ADJUST:  handlePPSAdjust(dir, enc, b1, b2); break;
            case Screen::PDO_SELECT:  handlePDOSelect(dir, enc, b1, b2); break;
            case Screen::PD_ANALYZER: handlePDAnalyzer(dir, enc, b1, b2); break;
            case Screen::SESSION:     handleSession(dir, enc, b1, b2);   break;
            case Screen::CLOUD:       handleCloud(dir, enc, b1, b2);     break;
            case Screen::SAFETY:      handleSafety(dir, enc, b1, b2);    break;
            case Screen::SYSTEM:      handleSystem(dir, enc, b1, b2);    break;
            default: break;
        }
    }

    // Display
    if (tmDisplay.due(T_DISPLAY)) {
        u8g2.clearBuffer();
        setFontM();
        if (sys.fault)              renderFault();
        else switch (ui.screen) {
            case Screen::MAIN:         renderMain();         break;
            case Screen::MENU:         renderMenu();         break;
            case Screen::PPS_ADJUST:   renderPPSAdjust();   break;
            case Screen::PDO_SELECT:   renderPDOSelect();   break;
            case Screen::PD_ANALYZER:  renderPDAnalyzer();  break;
            case Screen::SESSION:      renderSession();      break;
            case Screen::CLOUD:        renderCloud();        break;
            case Screen::SAFETY:       renderSafety();       break;
            case Screen::SYSTEM:       renderSystem();       break;
            case Screen::DISCONNECTED: renderDisconnected(); break;
            case Screen::DETECTING:    renderDetecting();    break;
            default:                   renderMain();         break;
        }
        u8g2.sendBuffer();
    }

    // Cloud
    if (WiFi.status() == WL_CONNECTED) {
        cloud.wifiOk = true;
        WiFi.localIP().toString().toCharArray(cloud.ipStr, 16);
        if (!mqtt.connected() && tmMqtt.due(T_MQTT_RETRY)) cloudConnect();
        mqtt.loop();
        if (cloud.mqttOk && tmCloud.due(cloud.interval)) cloudPublish();
    } else {
        cloud.wifiOk = cloud.mqttOk = false;
        if (tmWifi.due(T_WIFI_RETRY)) WiFi.reconnect();
    }

    digitalWrite(PIN_LED, sys.mosfetOn ? HIGH : LOW);
}

// ============================================================
//  PD CONTROL
// ============================================================
void pdInit() {
    pd.begin(true, true);
    pd.setProtectionConfig(false, false, true, true, true);
    pd.setOTPThreshold(120);
    pd.setDeratingThreshold(85);
    pd.setOVPOffset_mV(2000);
    pd.setOCPThreshold_mA(0);
}

bool pdWaitPDOs(uint32_t timeout) {
    uint32_t start = millis();

    while (millis() - start < timeout) {
        pd.task();

        uint8_t op = pd.getOpMode();

        if (op & OPMODE_LGCYMOD) {
            sys.mode = SysMode::LEGACY;
            ui.screen = Screen::MAIN;

            sys.fixedCount = 0;
            sys.ppsAvail = false;
            sys.ppsPdoIdx = 0;
            sys.negoV_mV = 5000;
            sys.negoI_mA = 0;
            ui.profileCursor = 0;

            return true;
        }

        if ((op & OPMODE_PDMOD) && pd.readAllPDOs() > 0) {
            return true;
        }

        delay(T_PDO_POLL);
    }

    return false;
}

void pdDetect() {
    uint16_t savedPpsV = sys.ppsSetV_mV;
    uint16_t savedPpsI = sys.ppsSetI_mA;
    uint8_t  savedFixedSel = sys.fixedSel;
    if (pd.readAllPDOs() == 0) {
        sys.mode  = pd.isLegacyConnected() ? SysMode::LEGACY : SysMode::DISCONNECTED;
        ui.screen = (sys.mode == SysMode::DISCONNECTED) ? Screen::DISCONNECTED : Screen::MAIN;
        return;
    }
    sys.fixedCount = 0; sys.ppsAvail = false; sys.ppsMaxV_mV = 5000;
    for (uint8_t i = 1; i <= AP33772S_MAX_PDO; i++) {
        const AP33772S_PDO &p = pd.getPDO(i);
        if (!p.valid) continue;
        if (p.type == PDO_TYPE_FIXED) {
            sys.fixedIdx[sys.fixedCount++] = i;
        } else if (p.type == PDO_TYPE_PPS) {
            sys.ppsAvail = true;
            if (p.maxVoltage_mV >= sys.ppsMaxV_mV) {
                sys.ppsPdoIdx  = i;
                sys.ppsMinV_mV = p.minVoltage_mV;
                sys.ppsMaxV_mV = p.maxVoltage_mV;
                sys.ppsMaxI_mA = p.maxCurrent_mA;
            }
        }
    }

    // Validate saved fixedSel
    if (sys.fixedSel >= sys.fixedCount) sys.fixedSel = 0;

   if (sys.fixedCount > 0) {
    sys.fixedSel = (savedFixedSel < sys.fixedCount) ? savedFixedSel : 0;
}

if (sys.ppsAvail) {
    sys.mode = SysMode::PPS;

    sys.ppsSetV_mV = constrain(
        savedPpsV,
        sys.ppsMinV_mV,
        sys.ppsMaxV_mV
    );

    sys.ppsSetI_mA = constrain(
        savedPpsI,
        (uint16_t)1000u,
        sys.ppsMaxI_mA
    );

} else if (sys.fixedCount > 0) {
    sys.mode = SysMode::PD_FIXED;
} else {
    sys.mode = SysMode::DISCONNECTED;
    ui.screen = Screen::DISCONNECTED;
    return;
}
    sys.outputReq = false;
    ui.screen = Screen::MAIN;
    pdApply(false);
}

void pdApply(bool smooth) {
    bool bigJump = abs((int32_t)sys.ppsSetV_mV - (int32_t)sys.negoV_mV) > 2000;
    if (!smooth || bigJump || sys.mode != SysMode::PPS) {
        digitalWrite(PIN_MOSFET, LOW); sys.mosfetOn = false; delay(20);
    }

    // LEGACY: no negotiation needed, just allow MOSFET control
    if (sys.mode == SysMode::LEGACY) {
        sys.negoV_mV = 5000;
        sys.negoI_mA = 0;
        mosfetUpdate();
        return;
    }

    int8_t rc = AP_ERR_NO_PDO;
    if (sys.mode == SysMode::PPS) {
        sys.ppsSetV_mV = constrain(sys.ppsSetV_mV, sys.ppsMinV_mV, sys.ppsMaxV_mV);
        sys.ppsSetI_mA = constrain(sys.ppsSetI_mA, (uint16_t)1000u, sys.ppsMaxI_mA);
        sys.ppsSetV_mV = (sys.ppsSetV_mV / 20u) * 20u;
        rc = pd.setPPSPDO(sys.ppsPdoIdx, sys.ppsSetV_mV, sys.ppsSetI_mA);
        tmPPS.last = millis();
    } else if (sys.mode == SysMode::PD_FIXED && sys.fixedCount > 0) {
        uint8_t idx = sys.fixedIdx[sys.fixedSel];
        rc = pd.setFixPDO(idx, pd.getPDO(idx).maxCurrent_mA);
    }

    if (rc == AP_OK && pd.waitForNegotiation(T_NEGO_WAIT) == AP_OK) {
        sys.negoV_mV = pd.getRequestedVoltage_mV();
        sys.negoI_mA = pd.getRequestedCurrent_mA();
        mosfetUpdate();
        // NOTE: nvSave() is NOT called here. Caller must call it when user confirms.
    } else {
        sys.negoFails++;
        faultTrigger("Nego Failed");
    }
}
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

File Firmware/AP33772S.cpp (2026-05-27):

/**
 *
 * Key encoding facts verified from datasheet Table 2 (PD_REQMSG):
 *   Fixed PDO  : VOLTAGE_SEL = 0x00  (ignored by chip)
 *   PPS APDO   : VOLTAGE_SEL = target_mV / 100   (100 mV per unit, SPR bit15=0)
 *   AVS APDO   : VOLTAGE_SEL = target_mV / 200   (200 mV per unit, EPR bit15=1)
 *   CURRENT_SEL: 0x0=1.00A … 0xF=5.00A  (250 mA steps from code 1 upward)
 *
 * ADC scaling (Table 19):
 *   VOLTAGE  0x11 : 16-bit LE, 1 LSB = 80 mV
 *   CURRENT  0x12 :  8-bit,    1 LSB = 24 mA
 *   VREQ     0x14 : 16-bit LE, 1 LSB = 50 mV
 *   IREQ     0x15 : 16-bit LE, 1 LSB = 10 mA
 *   VSELMIN  0x16 :  8-bit,    1 LSB = 200 mV  (default 0x19 = 5000 mV)
 *   OVPTHR   0x18 :  8-bit,    1 LSB = 80 mV   (default 0x19 = 2000 mV)
 *   OCPTHR   0x19 :  8-bit,    1 LSB = 50 mA
 */

#include "AP33772S.h"

// ─────────────────────────────────────────────────────────────────────────────
//  CONSTRUCTION
// ─────────────────────────────────────────────────────────────────────────────
AP33772S::AP33772S(TwoWire &wire, int8_t intPin)
    : _wire(wire),
      _intPin(intPin),
      _validPDOCount(0),
      _keepAliveActive(false),
      _keepAliveTimer(0),
      _keepAlivePDOIndex(0),
      _keepAliveVoltageSel(0),
      _keepAliveCurrentSel(0)
{
    memset(_pdoRaw,     0, sizeof(_pdoRaw));
    memset(_pdoDecoded, 0, sizeof(_pdoDecoded));
}

// ─────────────────────────────────────────────────────────────────────────────
//  begin()
// ─────────────────────────────────────────────────────────────────────────────
int8_t AP33772S::begin(bool enableEPR, bool enablePPS)
{
    // Probe device
    _wire.beginTransmission(AP33772S_I2C_ADDR);
    if (_wire.endTransmission() != 0) return AP_ERR_I2C;

    // Configure INT pin
    if (_intPin >= 0) pinMode(_intPin, INPUT);

    // PDCONFIG (0x05): enable EPR and/or PPS as requested
    uint8_t pdcfg = 0;
    if (enableEPR) pdcfg |= PDCFG_EPR_EN;
    if (enablePPS) pdcfg |= PDCFG_PPS_EN;
    if (!writeReg8(REG_PDCONFIG, pdcfg))          return AP_ERR_I2C;

    // CONFIG (0x04): enable all protections by default
    if (!writeReg8(REG_CONFIG,   CONFIG_ALL_EN))   return AP_ERR_I2C;

    // MASK (0x02): unmask STARTED, READY, NEWPDO, and all faults
    if (!writeReg8(REG_MASK,     MASK_ALL_FAULTS)) return AP_ERR_I2C;

    return AP_OK;
}

// ─────────────────────────────────────────────────────────────────────────────
//  waitForStartup()
// ─────────────────────────────────────────────────────────────────────────────
int8_t AP33772S::waitForStartup(uint32_t timeoutMs)
{
    uint32_t deadline = millis() + timeoutMs;
    while (millis() < deadline) {
        int16_t s = readReg8(REG_STATUS);
        if (s >= 0 && ((uint8_t)s & STATUS_STARTED)) return AP_OK;
        delay(10);
    }
    return AP_ERR_TIMEOUT;
}

// ─────────────────────────────────────────────────────────────────────────────
//  waitForPDOs()
// ─────────────────────────────────────────────────────────────────────────────
int8_t AP33772S::waitForPDOs(uint32_t timeoutMs)
{
    uint32_t deadline = millis() + timeoutMs;
    while (millis() < deadline) {
        int16_t s = readReg8(REG_STATUS);
        if (s >= 0) {
            uint8_t st = (uint8_t)s;
            if ((st & STATUS_NEWPDO) && (st & STATUS_READY)) return AP_OK;
        }
        delay(50);
    }
    return AP_ERR_TIMEOUT;
}

// ─────────────────────────────────────────────────────────────────────────────
//  _currentEncode()  —  mA → 4-bit CURRENT_SEL code
//
//  Per datasheet Table 2 / official example firmware:
//    code 0  → < 1.25 A (nominally 1.00 A)
//    code 1  → 1.25 A
//    code 2  → 1.50 A
//    …
//    code 15 → 5.00 A
//  Each step above code 0 is 250 mA.
// ─────────────────────────────────────────────────────────────────────────────
uint8_t AP33772S::_currentEncode(uint16_t mA)
{
    if (mA < 1250) return 0;
    if (mA >= 5000) return 15;
    int code = (((int)mA - 1250) / 250) + 1;
    return (code > 15) ? 15 : (uint8_t)code;
}

// ─────────────────────────────────────────────────────────────────────────────
//  _currentDecode()  —  4-bit code → approximate mA
// ─────────────────────────────────────────────────────────────────────────────
uint16_t AP33772S::_currentDecode(uint8_t code)
{
    if (code == 0)  return 1000;
    if (code == 15) return 5000;
    return (uint16_t)(1250 + (code - 1) * 250);
}

// ─────────────────────────────────────────────────────────────────────────────
//  _decodePDO()  —  parse raw 16-bit PDO word into AP33772S_PDO struct
//
//  PDO word layout (datasheet – SRC_SPRandEPR_PDO_Fields):
//    bits[7:0]   voltage_max
//    bits[9:8]   voltage_min (APDO) or peak_current (Fixed)
//    bits[13:10] current_max (4-bit range code)
//    bit[14]     type  (0 = Fixed, 1 = APDO)
//    bit[15]     detect / valid
//
//  Voltage scaling:
//    SPR Fixed  : voltage_max × 100 mV
//    EPR Fixed  : voltage_max × 200 mV
//    PPS        : voltage_max × 100 mV  (SPR slot)
//    AVS        : voltage_max × 200 mV  (EPR slot)
// ─────────────────────────────────────────────────────────────────────────────
void AP33772S::_decodePDO(uint8_t idx)
{
    // idx is 0-based (0–12 → PDO1–PDO13)
    const PDO_RAW_T  &raw = _pdoRaw[idx];
    AP33772S_PDO     &dec = _pdoDecoded[idx];

    dec.index = idx + 1;
    dec.raw   = raw.word;
    dec.valid = (raw.fields.detect == 1);
    dec.isEPR = (idx >= AP33772S_SPR_PDO_COUNT); // slots 7–12 = EPR

    if (!dec.valid) {
        dec.type = PDO_TYPE_NONE;
        dec.minVoltage_mV = dec.maxVoltage_mV = dec.maxCurrent_mA = 0;
        dec.currentCode   = 0;
        return;
    }

    dec.currentCode   = raw.fields.current_max;
    dec.maxCurrent_mA = _currentDecode(dec.currentCode);

    if (raw.fields.type == 0) {
        // ── Fixed PDO ────────────────────────────────────────────────────────
        dec.type = PDO_TYPE_FIXED;
        uint16_t scale    = dec.isEPR ? 200u : 100u;
        dec.maxVoltage_mV = (uint16_t)raw.fields.voltage_max * scale;
        dec.minVoltage_mV = dec.maxVoltage_mV;   // Fixed = single voltage point

    } else if (!dec.isEPR) {
        // ── PPS APDO (type=1, SPR slot, index 1–7) ───────────────────────────
        dec.type          = PDO_TYPE_PPS;
        dec.maxVoltage_mV = (uint16_t)raw.fields.voltage_max * 100u;

        // voltage_min field interpretation per datasheet:
        //   0 = reserved, 1 = ≥3300 mV, 2 = 3300 < min ≤ 5000 mV, 3 = other
        switch (raw.fields.voltage_min) {
            case 2:  dec.minVoltage_mV = 5000; break;
            default: dec.minVoltage_mV = 3300; break;  // conservative: 3.3 V floor
        }

    } else {
        // ── AVS APDO (type=1, EPR slot, index 8–13) ──────────────────────────
        dec.type          = PDO_TYPE_AVS;
        dec.maxVoltage_mV = (uint16_t)raw.fields.voltage_max * 200u;
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
